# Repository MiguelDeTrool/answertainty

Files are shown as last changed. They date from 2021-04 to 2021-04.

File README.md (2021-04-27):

# answertainty
Simple Arduino Nano based pseudorandom Eurorack module

answertainty

Answertainty creates pseudorandom signals. It is inspired by NLC's Sloths, and Bogaudio's Walk. I must warn anyone attempting this that I have not tested these exact PCBs, only an earlier prototype, that I then made minor modifications to for this version. I am quite confident that they will work, and feel free to send me a message if you decide to try this out.

The "Gate" output changes to 0v or 5v randomly. The further the pot is turned right, the more frequently it changes state.

The "Slow" outputs create slowly evolving continuous control voltages, from about -5v to +5v. The further the pot is turned right, the faster it evolves.

The "Fast" output does the same as the "Slow" outputs, but responds to the pot in the opposite direction.

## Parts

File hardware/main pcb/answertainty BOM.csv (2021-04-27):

Designator | Package | Quantity | Designation
C7,C6 | C_Disc_D3.8mm_W2.6mm_P2.50mm | 2 | 100n
R7,R6,R5 | R_Axial_DIN0204_L3.6mm_D1.6mm_P5.08mm_Horizontal | 3 | 10K
J4,J1,J3,J2 | PJ302M | 4 | AudioJack2_SwitchT
A1 | Arduino_Nano | 1 | Arduino_Nano_v3.x
C4,C5,C3,C2,C1 | CP_Radial_D6.3mm_P2.50mm | 5 | 0,0001
R15 | R_Axial_DIN0204_L3.6mm_D1.6mm_P5.08mm_Horizontal | 1 | 2K
R14 | R_Axial_DIN0204_L3.6mm_D1.6mm_P5.08mm_Horizontal | 1 | 1K
R13,R12,R11 | R_Axial_DIN0204_L3.6mm_D1.6mm_P5.08mm_Horizontal | 3 | 1000
R10,R9,R8 | R_Axial_DIN0204_L3.6mm_D1.6mm_P5.08mm_Horizontal | 3 | 5K
R4,R3,R2,R1 | R_Axial_DIN0204_L3.6mm_D1.6mm_P5.08mm_Horizontal | 4 | 330
J5 | PinHeader_2x05_P2.54mm_Vertical | 1 | IDC 02x05 connector
RV1 | Potentiometer_Alps_RK163_Single_Horizontal | 1 | 10K
U1 | DIP-14_W7.62mm_Socket_LongPads | 1 | TL074

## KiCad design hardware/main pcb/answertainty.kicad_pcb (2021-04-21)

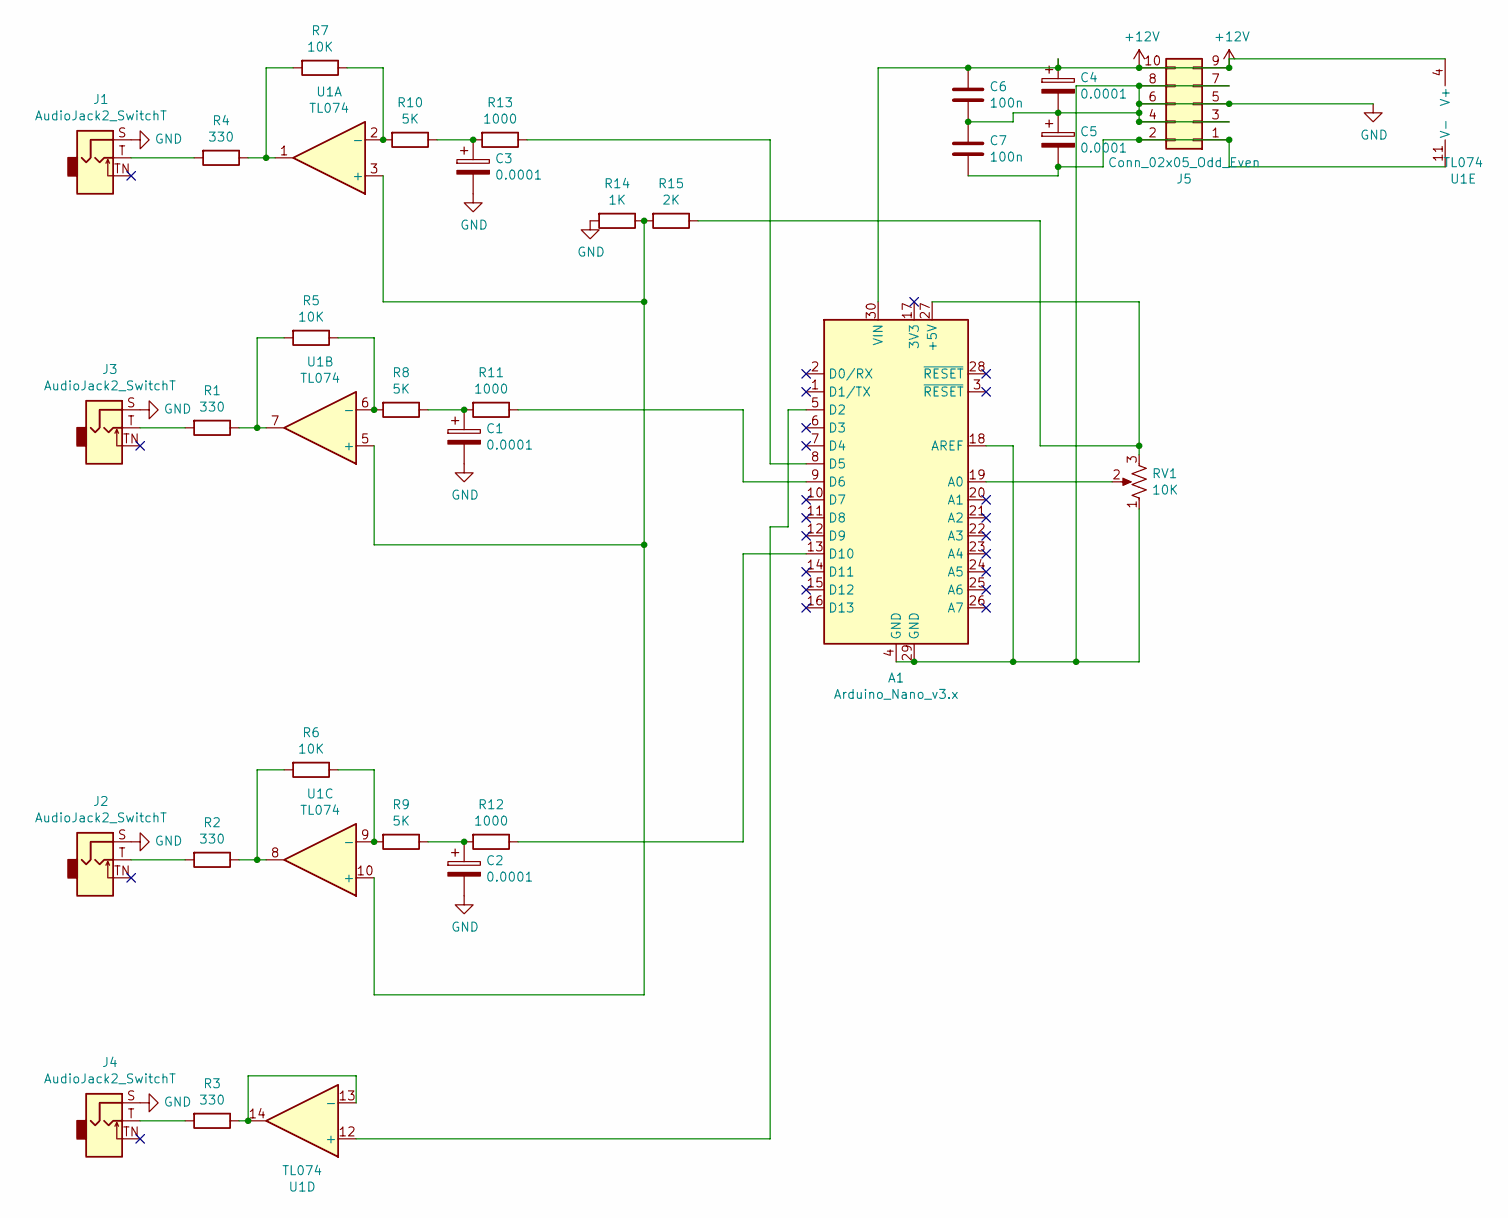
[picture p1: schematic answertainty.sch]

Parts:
A1: Arduino_Nano_v3.x; Arduino_Nano
C1, C2, C3, C4, C5: 0.0001; CP_Radial_D6.3mm_P2.50mm
C6, C7: 100n; C_Disc_D3.8mm_W2.6mm_P2.50mm
J1, J2, J3, J4: AudioJack2_SwitchT; PJ302M
J5: Conn_02x05_Odd_Even; PinHeader_2x05_P2.54mm_Vertical
R1, R2, R3, R4: 330; R_Axial_DIN0204_L3.6mm_D1.6mm_P5.08mm_Horizontal
R5, R6, R7: 10K; R_Axial_DIN0204_L3.6mm_D1.6mm_P5.08mm_Horizontal
R8, R9, R10: 5K; R_Axial_DIN0204_L3.6mm_D1.6mm_P5.08mm_Horizontal
R11, R12, R13: 1000; R_Axial_DIN0204_L3.6mm_D1.6mm_P5.08mm_Horizontal
R14: 1K; R_Axial_DIN0204_L3.6mm_D1.6mm_P5.08mm_Horizontal
R15: 2K; R_Axial_DIN0204_L3.6mm_D1.6mm_P5.08mm_Horizontal
RV1: 10K; Potentiometer_Alps_RK163_Single_Horizontal
U1: TL074; DIP-14_W7.62mm_Socket_LongPads

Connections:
+12V: A1.30 (VIN), C4.1, C6.1, J5.9, J5.10, U1.4 (V+)
GND: A1.4 (GND), A1.18 (AREF), A1.29 (GND), C1.2, C2.2, C3.2, C4.2, C5.1, C6.2, C7.1, J1.S, J2.S, J3.S, J4.S, J5.3, J5.4, J5.5, J5.6, J5.7, J5.8, R14.2, RV1.1
unnamed: A1.5 (D2), U1.12 (+)
unnamed: A1.8 (D5), R13.1
unnamed: A1.9 (D6), R11.1
unnamed: A1.13 (D10), R12.1
unnamed: A1.19 (A0), RV1.2
unnamed: A1.27 (+5V), R15.1, RV1.3
unnamed: C1.1, R8.1, R11.2
unnamed: C2.1, R9.1, R12.2
unnamed: C3.1, R10.1, R13.2
unnamed: C5.2, C7.2, J5.1, J5.2, U1.11 (V-)
unnamed: J1.T, R4.2
unnamed: J2.T, R2.2
unnamed: J3.T, R1.2
unnamed: J4.T, R3.2
unnamed: R1.1, R5.2, U1.7
unnamed: R2.1, R6.2, U1.8
unnamed: R3.1, U1.13 (-), U1.14
unnamed: R4.1, R7.2, U1.1
unnamed: R5.1, R8.2, U1.6 (-)
unnamed: R6.1, R9.2, U1.9 (-)
unnamed: R7.1, R10.2, U1.2 (-)
unnamed: R14.1, R15.2, U1.3 (+), U1.5 (+), U1.10 (+)

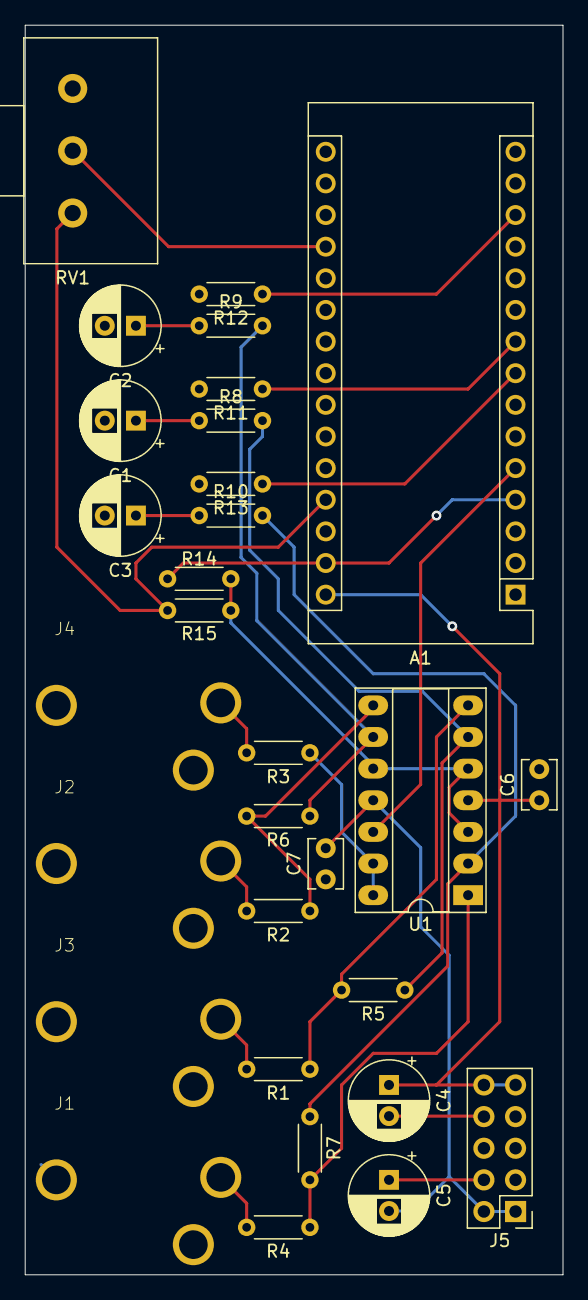
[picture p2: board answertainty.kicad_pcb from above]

Board: 2 copper layers, 43.2 x 100.3 mm, 30 parts (0 on the bottom side), 24 nets.

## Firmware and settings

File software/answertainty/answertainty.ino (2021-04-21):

int cvRateSlow = 0;
int cvRateFast = 0;
int cvOut1 = 511;
int cvOut2 = 511;
int cvOut3 = 511;
int gateTest = 0;

int pot = A0;
int cvJack1 = 5;
int cvJack2 = 6;
int cvJack3 = 10;
int gateJack1 = 2;

void setup() {

 // to modify PWM frequency if wanted, not properly tested
//  TCCR0B = TCCR0B & B11111000 | B00000001; // for PWM frequency of 62500.00 Hz for 5 and 6
//  TCCR1B = TCCR1B & B11111000 | B00000001; // for PWM frequency of 31372.55 Hz for 10

  pinMode(pot, INPUT);
  pinMode(cvJack1, OUTPUT);
  pinMode(cvJack2, OUTPUT);
  pinMode(cvJack3, OUTPUT);
  pinMode(gateJack1, OUTPUT);

}

void loop() {

  cvRateSlow = map(analogRead(pot), 0, 1023, 2, 99); // Low needs to be even, high needs to be odd. These figures can be set as you wish, to define rate of change
  if ( (cvRateSlow % 2) == 0) {
    cvRateSlow = cvRateSlow + 1;
  }

  cvRateFast = map(analogRead(pot), 0, 1023, 99, 2); // Opposite mapping
  if ( (cvRateFast % 2) == 0) {
    cvRateFast = cvRateFast + 1;
  }

  cvOut1 = cvOut1 + random(cvRateSlow) - cvRateSlow / 2;
  cvOut2 = cvOut2 + random(cvRateSlow) - cvRateSlow / 2;
  cvOut3 = cvOut3 + random(cvRateFast) - cvRateFast / 2;

  cvOut1 = constrain(cvOut1, 0, 1023);
  cvOut2 = constrain(cvOut2, 0, 1023);
  cvOut3 = constrain(cvOut3, 0, 1023);

  analogWrite(cvJack1, map(cvOut1, 0, 1023, 0, 255));
  analogWrite(cvJack2, map(cvOut2, 0, 1023, 0, 255));
  analogWrite(cvJack3, map(cvOut3, 0, 1023, 0, 255));


  gateTest = random(map(analogRead(pot), 0, 1023, 1700, 10)); // You can experiment with the last two figures for different rates of gate state changes. Maybe try a logarithmic curve.
  
  if (gateTest == 0) {
    digitalWrite(gateJack1, !digitalRead(gateJack1));
  }

}
